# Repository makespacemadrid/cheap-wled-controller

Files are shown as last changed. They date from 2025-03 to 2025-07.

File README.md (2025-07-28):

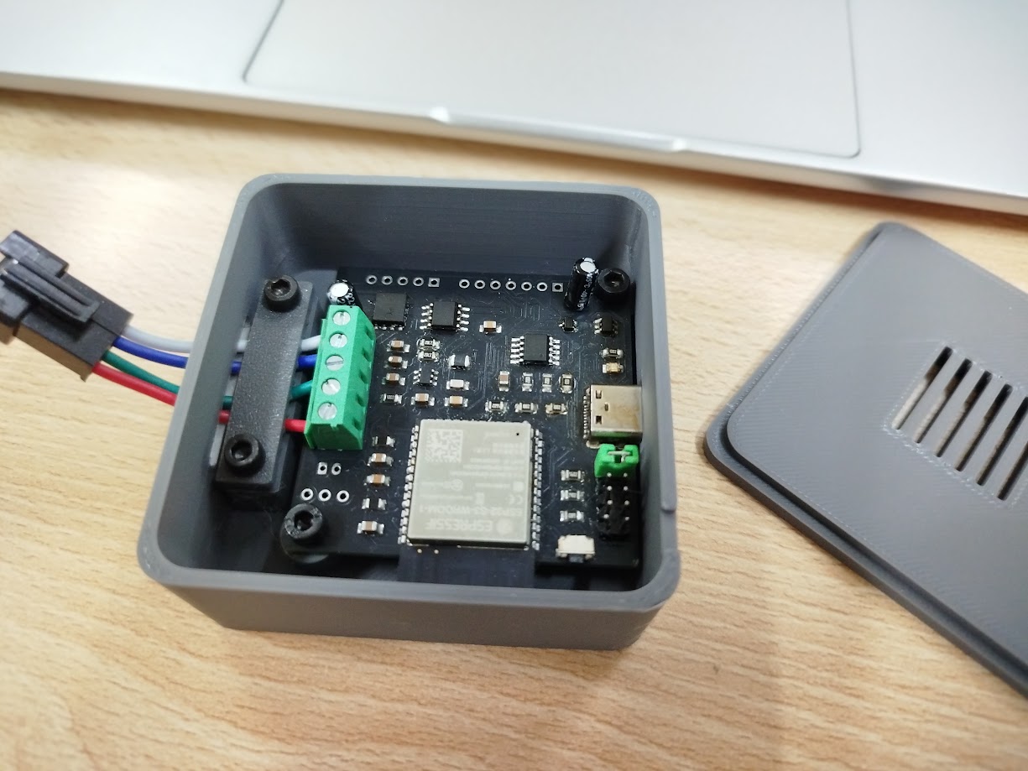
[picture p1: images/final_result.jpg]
resultado final

Este proyecto nace de una práctica con Kicad en uno de los talleres de Makespace (slides de nuestro compañero Pablo Garrido [aquí](https://docs.google.com/presentation/d/1glYFRo9XCKRI-qDjp1DA8M3mJohLk-lrxx0JoBPsboM/edit?usp=drive_link)),
donde se diseñó el esquemático y el enrutado de la pcb para posterior fabricación de la misma en JLCPCB.

Continuando con el proceso lógico de aprendizaje, 
ahora este proyecto pretende servir como una primera aproximación en la práctica de soldadura SMD (componentes de montaje superficiales), 
así como fabricación de stencil usando una CNC (maquina de control numérico).

Junto al proyecto Kicad también se encuentran los stl de la carcasa para imprimirla en 3d.

El repositorio con el proyecto Kicad: https://github.com/makespacemadrid/cheap-wled-controller718714

Esta pcb tiene la particularidad de usar para su alimentación un usb c con PD (Power delivery), lo que permite negociar diferentes votlajes y de este modo usar tiras led que trabajen a 5v, 9v, 12v, etc.

## BOM 
### PCB
- [CH224K USB PD Protocol Sink Chip IC 10Pcs/lot](https://www.aliexpress.com/item/1005005284290184.html?spm=a2g0o.order_list.order_list_main.5.21ef194dDFnpwX)
- [AMS1117 3.3](https://www.aliexpress.com/item/1005005350284100.html?spm=a2g0o.order_list.order_list_main.544.21ef194dDFnpwX)
- ESP32-S3-WROOM-1-N4R
- [TPS54202DDC](https://lcsc.com/product-detail/DC-DC-Converters_TI-TPS54202DDCR_C191884.html?s_z=n_C191884)
- [MX5014S](https://lcsc.com/product-detail/Gate-Drivers_Wuxi-Maxinmicro-MX5014S_C5359091.html?s_z=n_C5359091)
- [ESDA25W](https://lcsc.com/product-detail/ESD-and-Surge-Protection-TVS-ESD_TECH-PUBLIC-ESDA25W_C3021136.html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)
- [receptor IR](https://lcsc.com/product-detail/Infrared-Receivers_VISHAY_TSOP38238_TSOP38238_C141632.html)
- diodo led footprint 0805
- [conector usb C](https://lcsc.com/product-detail/USB-Connectors_Korean-Hroparts-Elec-TYPE-C-31-M-12_C165948.html?s_z=n_C165948)
- [pin-header](https://lcsc.com/product-detail/Pin-Headers_Megastar-ZX-PZ2-0-2-5PZZ_C7501288.html?s_z=n_C7501288)
- [mosfet canal N](https://lcsc.com/product-detail/MOSFETs_YANGJIE-YJG100N04A_C919580.html?s_z=n_C919580)

### Stencil
- [fresa 3.175mmx15Dx0.1, CN](https://www.aliexpress.com/item/4000966103866.html?spm=a2g0o.order_list.order_list_main.509.21ef194dDFnpwX)
- una lata de refresco
- cinta de carrocero
- cinta de doble cara sin espuma. La que usamos nosotros es esta, comprada en papelerías Folder:
[comprada en papelerías Folder](/images/cinta_doble_cara.png)

### Carcasa
- 4 tornillos M3x6
- 4 insertos metálicos [Length 4mm, M3 (OD 5mm)](https://es.aliexpress.com/item/1005004870993068.html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)

## Tiras led
Las tiras led compatibles con el firmware son: https://kno.wled.ge/basics/compatible-led-strips/
- La tira led que usamos en el taller es esta: [WS2813 DC5V, White PCB, 2m 60 IP65](https://es.aliexpress.com/item/1005004289391906.html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)
- Para la alimentación sirve cualquier cargador de móvil con carga rápida, IKEA tiene [estos](https://www.ikea.com/es/es/p/sjoss-cargador-usb-1-puerto-30-w-carga-rapida-50549412/) a muy buen precio
- [conectores hembra y macho JST SM de 4 pines](https://es.aliexpress.com/item/1005004615616698.html)

## Fabricación de stencil
Usaremos el software Flatcam, en el que cargamos la capa "paste top" del gerber que generamos en Kicad para enviar a fabricar la PCB.
Esta capa contiene la geometría de los pads de todos los componentes. 

El proceso lo vamos a llevar a cabo con una fresa de 30 grados y 0.1 de diámetro. Asumiendo que la lata de refresco tiene un grosor de 0.2mm.
Las capturas de los pasos a seguir son las siguientes:

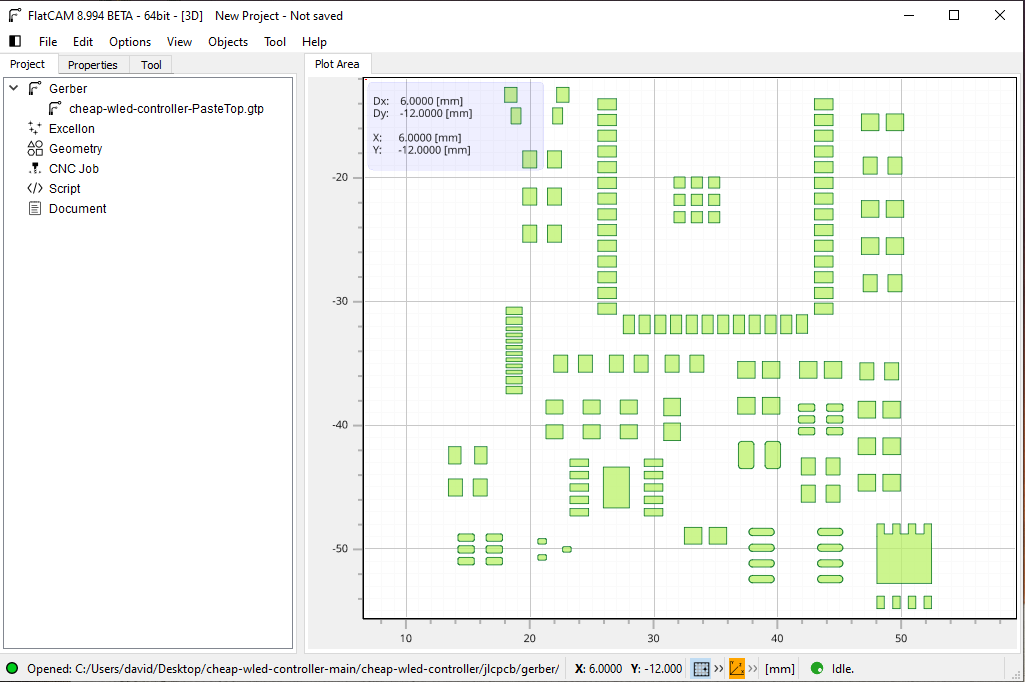
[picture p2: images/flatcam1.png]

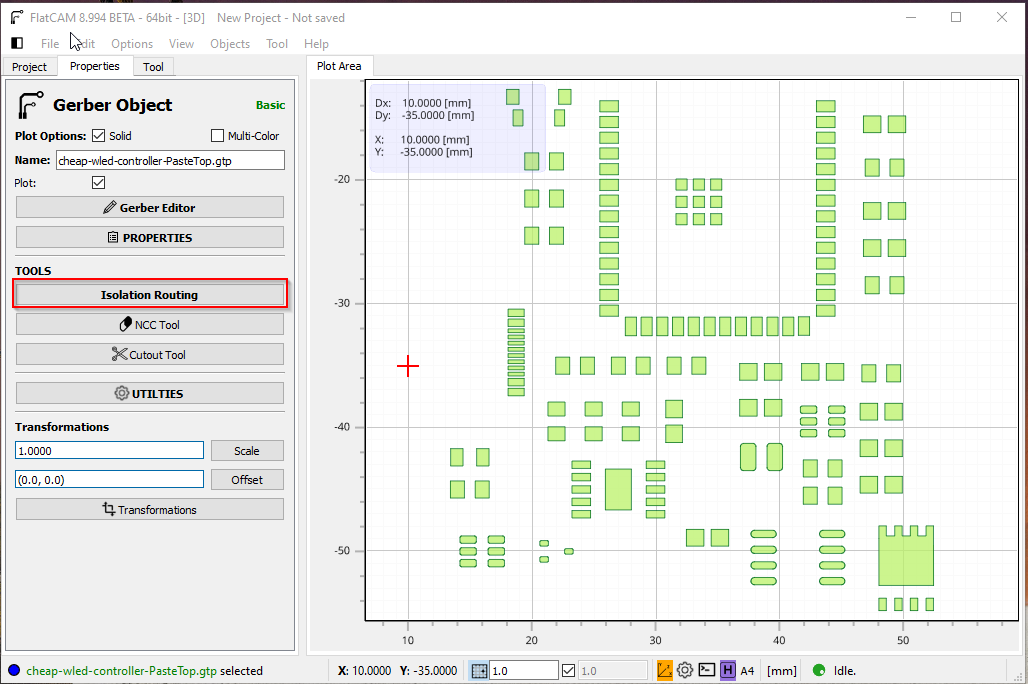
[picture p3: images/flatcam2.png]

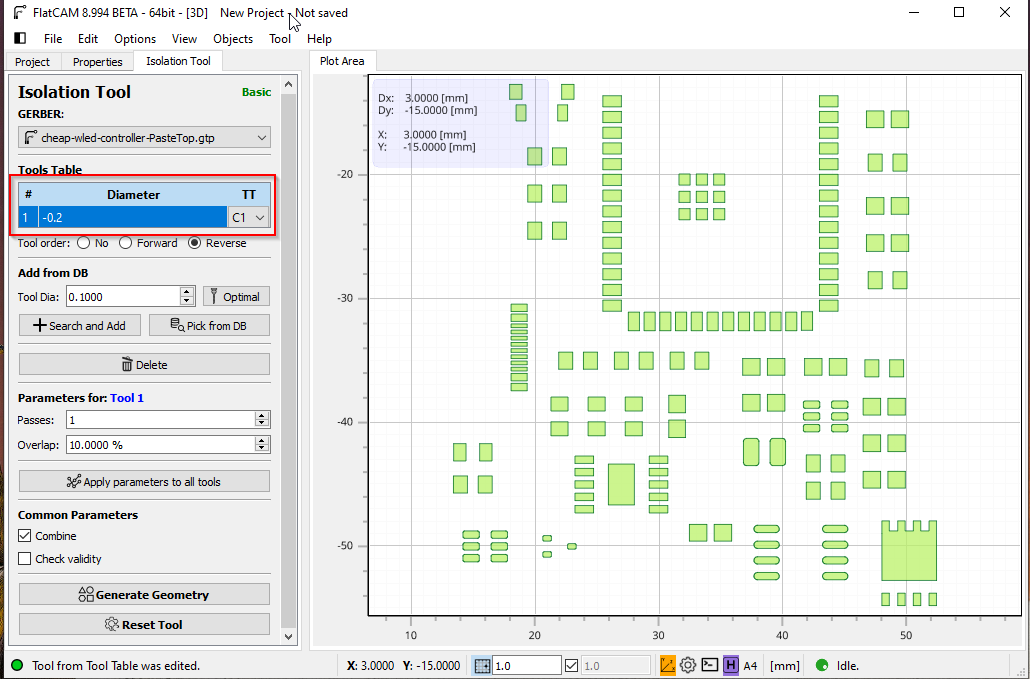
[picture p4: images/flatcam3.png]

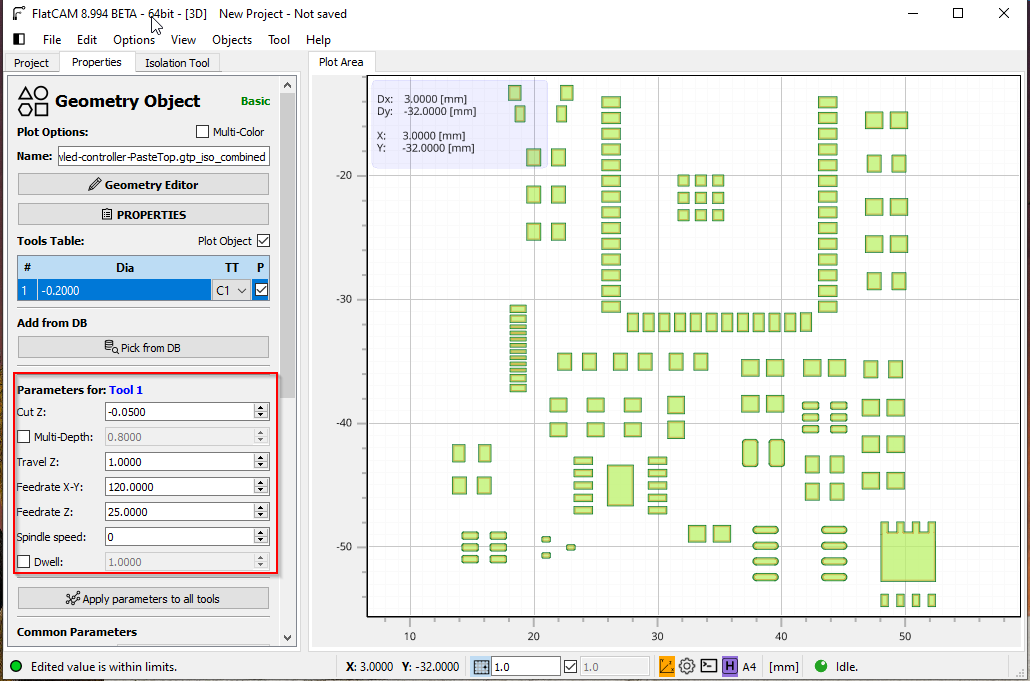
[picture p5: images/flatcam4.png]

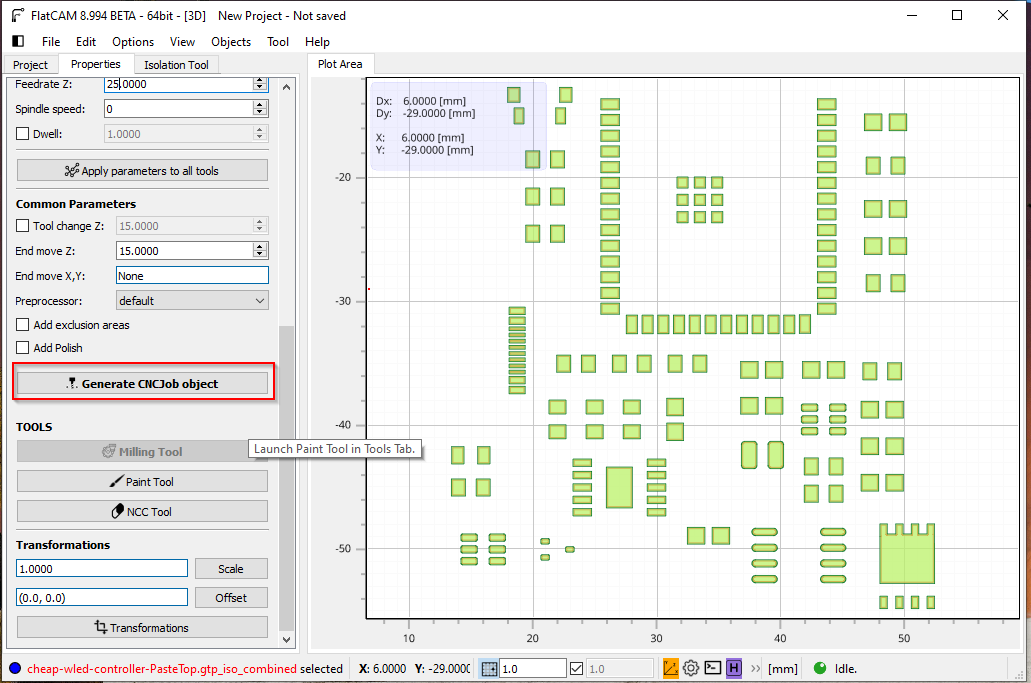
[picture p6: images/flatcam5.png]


El gcode generado finalmente lo hemos subido [aquí](/includes/paste_top.gcode).

## Flasheo y configuración de firmware WLED

### Flasheo

En nuestro caso estamos usando un esp32 s3 con 4MB, por lo que vamos a flashear desde la web: https://wled-install.github.io/

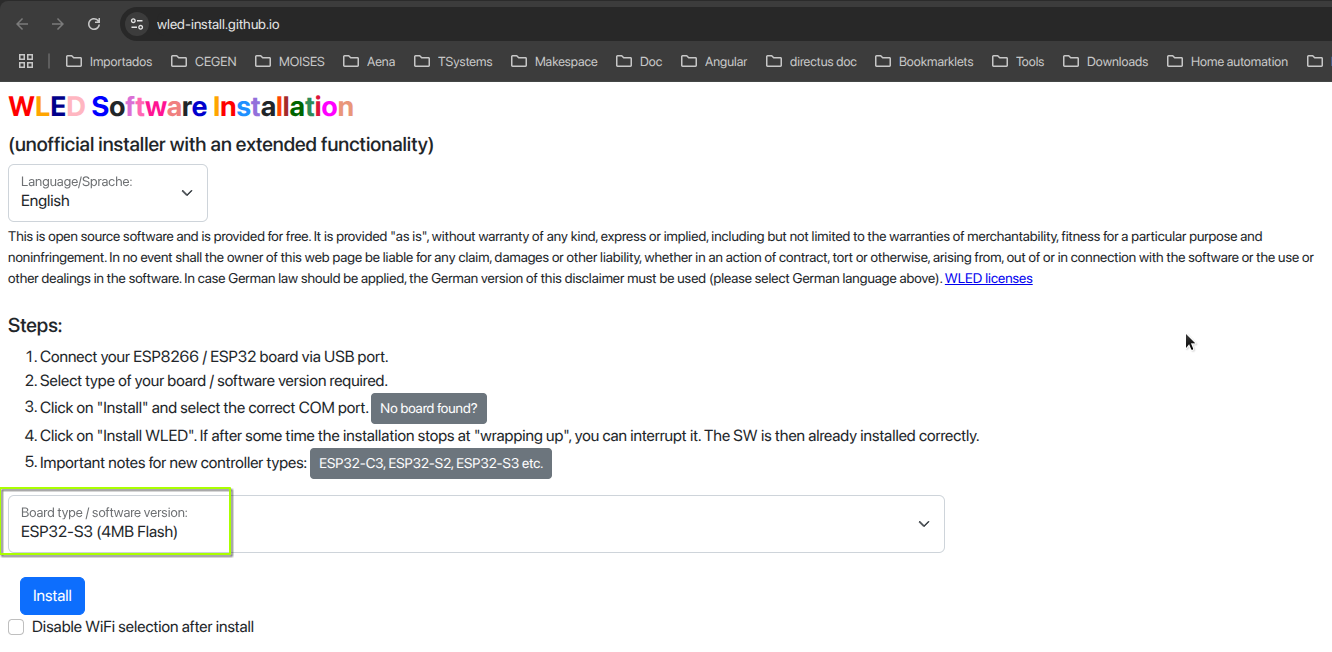
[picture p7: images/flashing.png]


### Configuración
En LED preferences:

La configuración de la tira:

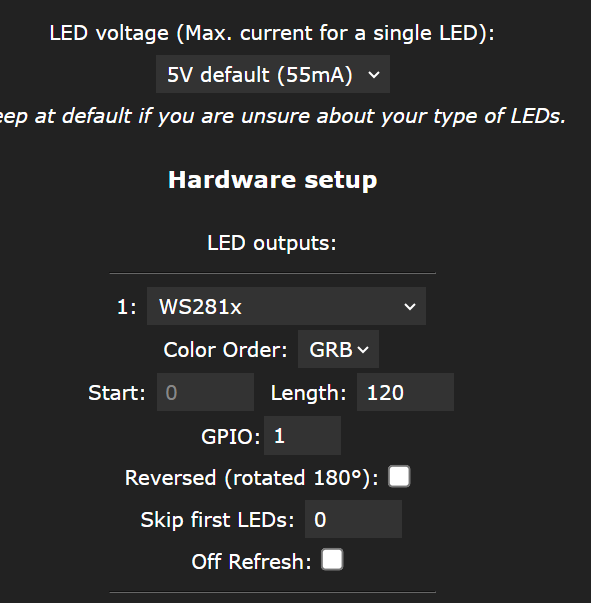
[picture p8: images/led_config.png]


La configuración del mosfet para apagar la tira:



El botón en placa permite encender y apagar la tira manualmente:



Para configurar el mando usaremos [este](/includes/18-key-ir.json) fichero json.



## Software necesario
- [Kicad](https://www.kicad.org/): Diseño pcb y generación de gerbers.
- [Flatcam](http://flatcam.org/): **Solo windows (adjuntamos el gcode ya generado)** Creación de gcode a partir del gerber para la fabricación del stencil
- [gSender](https://sienci.com/gsender/?srsltid=AfmBOopYPgWM8177GG6Q0knLP97hrF1G2skJw3ewIg3omObme7XnkDx5): Comunicación con la CNC para enviar el gcode
- [OrcaSlicer](https://orca-slicer.com/): Cualquier slicer para impresora 3d para fabricar la carcasa.

## Esquema de la placa

En este apartado se describen los componentes principales del circuito para gestionar la alimentación y regulación del voltaje de la tira LED.

---

### Información sobre el power delivery

📄 [UPD301A USB Power Delivery Operation](/datasheet/AN3265MicroChip.pdf)

📄 [A Primer on USB Type-C® and USB Power Delivery Applications and Requirements](/datasheet/PowerDeliveryTexas.pdf)

### 🔌 Conector USB-C

El conector USB-C que se utiliza en la placa tiene doce patillas con una separación muy pequeña entre cada una de ellas; además, en los dos extremos se encuentran los pines de alimentación (GND y VBUS), por lo que una mala soldadura podría generar un cortocircuito. 

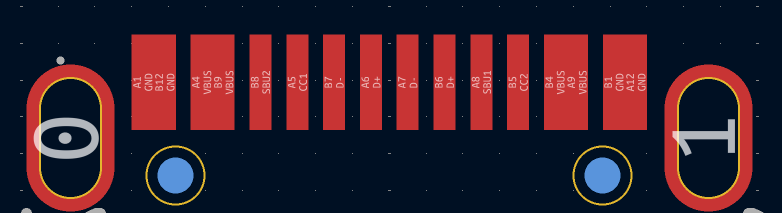
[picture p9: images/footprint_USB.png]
Connector


> **Es importante que antes de conectar la placa se mida la resistencia entre los pines de alimentación para comprobar que no haya cortocircuito 🔥.**

---

### CH224K

El CH224K es el componente encargado de gestionar el protocolo *power delibery* (PD).

📄 [Descargar datasheet](https://github.com/makespacemadrid/cheap-wled-controller/blob/main/datasheet/ch224k.pdf)

- **Encapsulado:** ESSOP-10
- **Distribución de pines:**

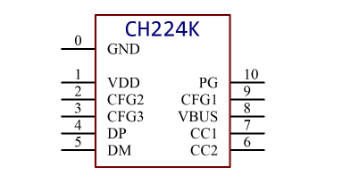
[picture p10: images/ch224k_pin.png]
Pin
  

| Pin No. | Pin name | Pin type | Pin description |
|---|---|---|---|
| 0 | GND | Power | Ground. Heat dissipation EPAD. |
| 1 | VDD | Power | Operating power input. Requires external 1uF decoupling capacitor. Connected in series with a resistor to VBUS. |
| 4, 5 | DP, DM | Input/Output | USB data line |
| 6, 7 | CC1, CC2 | Input/Output | Type-C CC data line |
| 2, 3, 9 | CFG1, CFG2, CFG3 | Analog input | Power configuration input |
| 8 | VBUS | Analog input | Voltage detection input. Connected in series with a resistor to external VBUS.  |
| 10 | PG | Open-drain output | Indicates Power Good by default. Active low. Can be customized. |

- **Configuración de voltaje de salida:**

  Los pines encargados de  configurar la salida del voltaje son el 2, el 3 y el 9. En este caso solo se utiliza el pin 9, por lo que en función de la resistencia que se conecte a este pin, el voltaje de salida variará entre 5 y 20 voltios.

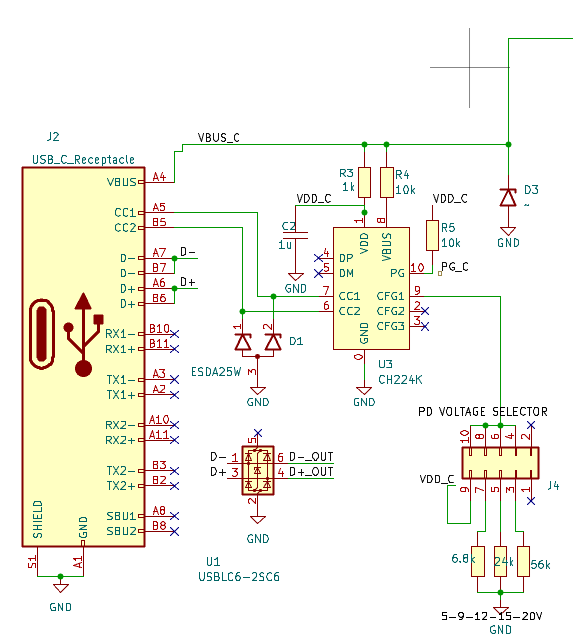
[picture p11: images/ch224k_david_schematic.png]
Schematic
  

   >Por ejemplo, si se conecta una resistencia de 10 kΩ del pin 9 a tierra, el voltaje de salida (VBUS_CONN) será de 5 V.

  | Resistance on CFG to VDD | Request-voltage |
  |--------------------------|-----------------|
  | 10KΩ                     | 5V              |
  | 20KΩ                     | 9V              |
  | 47KΩ                     | 12V             |
  | 100KΩ                    | 15V             |
  | 200KΩ                    | 20V             |

---
### TPS54202

El voltaje que sale del CH224K entra en el *buck converter* TPS54202, que será el encargado de generar los 5 voltios estables del circuito.

📄 [Descargar datasheet](/datasheet/tps54202.pdf)

- **Encapsulado:** SOT-23
  
- **Distribución de pines:**

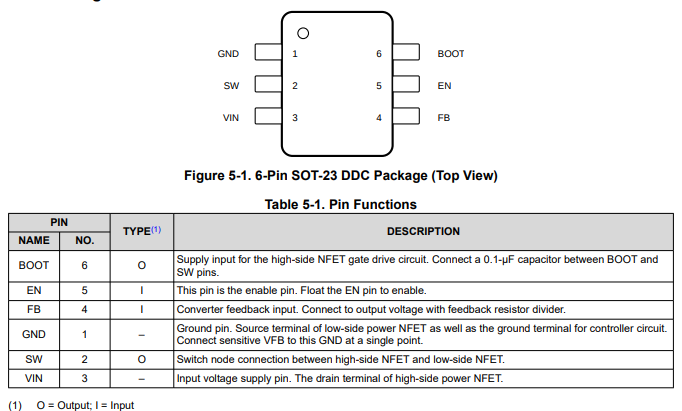
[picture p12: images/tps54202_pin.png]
Distribución de pines TPS54202
  

- **Configuración del circuito:**
  
  En el esquema del circuito se puede observar la configuración del componente, compuesta por resistencias, condensadores y la bobina L2, que mediante su carga (en forma de campo magnético) y descarga genera la corriente necesaria para alimentar los condensadores, que estabilizarán los 5 voltios de salida (+5V).

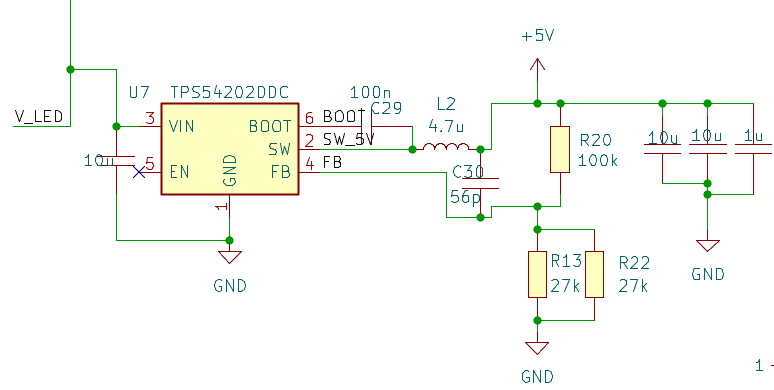
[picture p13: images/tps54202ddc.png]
  

---
### AMS1117 3-3V

Una vez que se ha generado el voltaje +5V, el regulador de voltaje lineal (LDO) AMS1117 comienza a trabajar para entregar los 3,3V. Hay que tener en cuenta que la corriente máxima que puede entregar este regulador es de 1A. 

📄 [Descargar datasheet](/datasheet/ams1117.pdf)

- **Distribución de pines:**

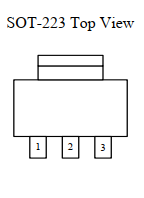
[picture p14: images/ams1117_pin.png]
Distribución de pines AMS1117
  

  > PIN 1: GND
  >
  > PIN 2: VOUT
  >
  > PIN 3: VDD

- **Configuración del circuito:**
  
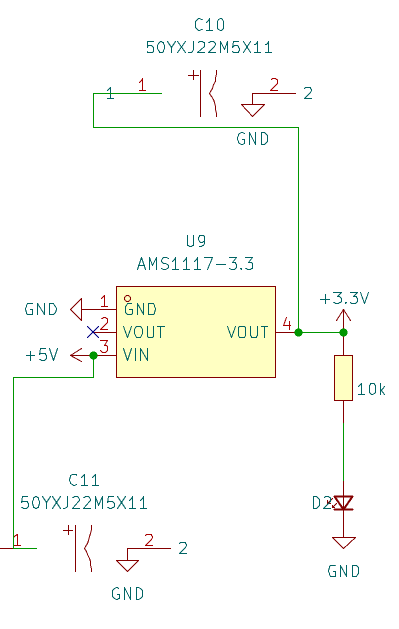
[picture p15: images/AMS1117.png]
  

---
### ESP32-S3-WROOM-1-N4R2

📄 [Descargar datasheet](/datasheet/esp32-s3.pdf)

- **Distribución de pines:**

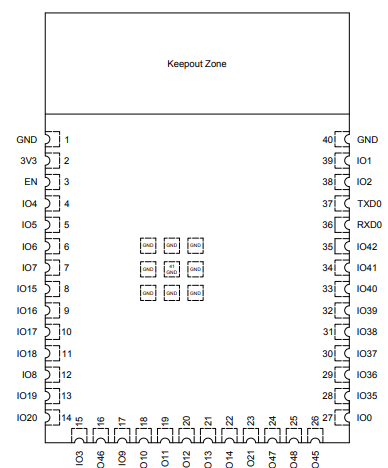
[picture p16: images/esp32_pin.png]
Distribución de pines ESP32-S3-WROOM-1-N4R2
  

- **Configuración del circuito:**
  
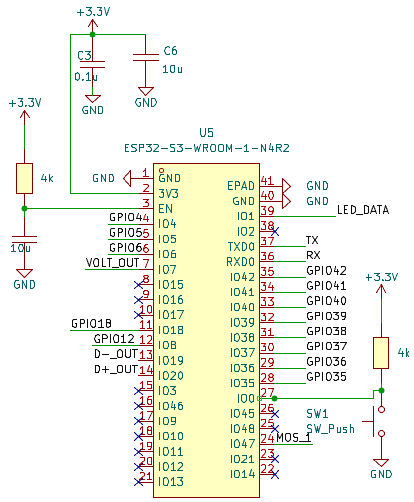
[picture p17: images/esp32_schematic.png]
Schematic
  

---
### MX5014S

 La tira LED se alimenta a través del voltaje que se genera en el MOSFET Q3, que está controlado por el MX5014S, y que a su vez responde del IO47 del ESP32.

📄 [Descargar datasheet](/datasheet/mx5014s.pdf)

- **Distribución de pines:**
  
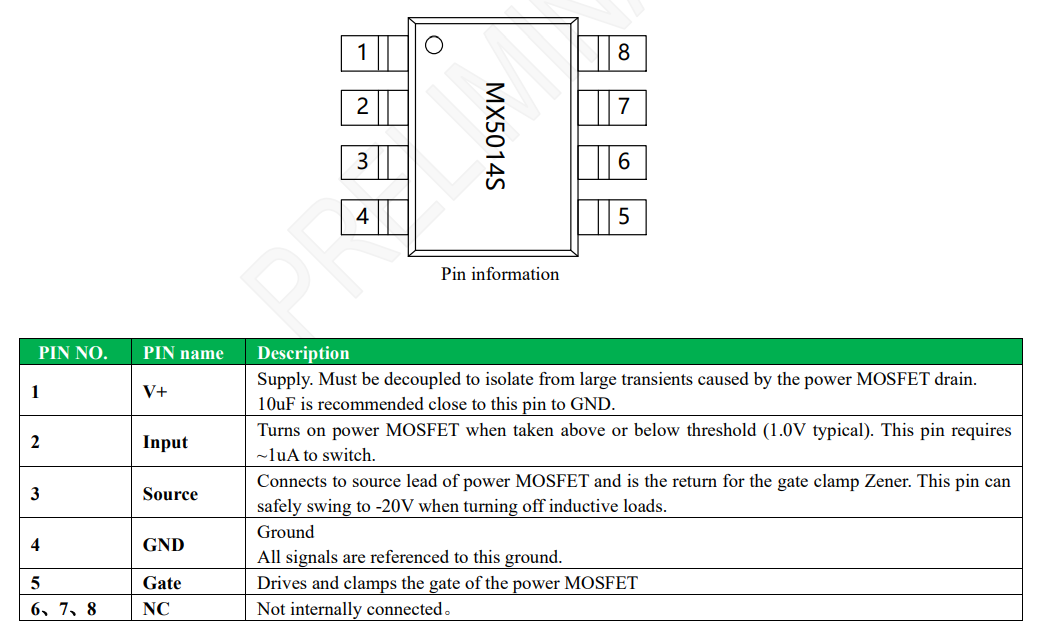
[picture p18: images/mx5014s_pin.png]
Distribución de los pines
  

- **Configuración del circuito:**
  
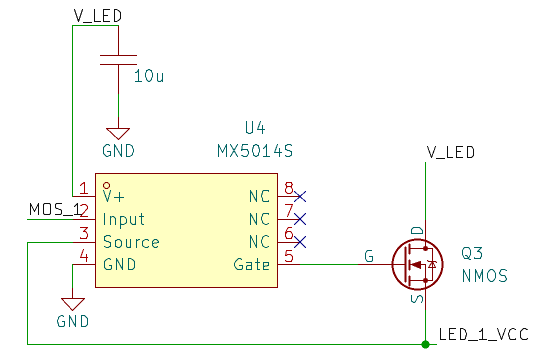
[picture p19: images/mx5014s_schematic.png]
Schematic
  

## Líneas de voltaje principales

|Línea|Voltaje|Componente|
|-----|---|---|
|V_LED_|5-20V|CH224K|
|+5V|5V|TPS54202|
|+3.3V|3.3V|AMS1117|
|LED_1_VCC|5-20V|Q3

---
## Stencil con los valores de los componentes

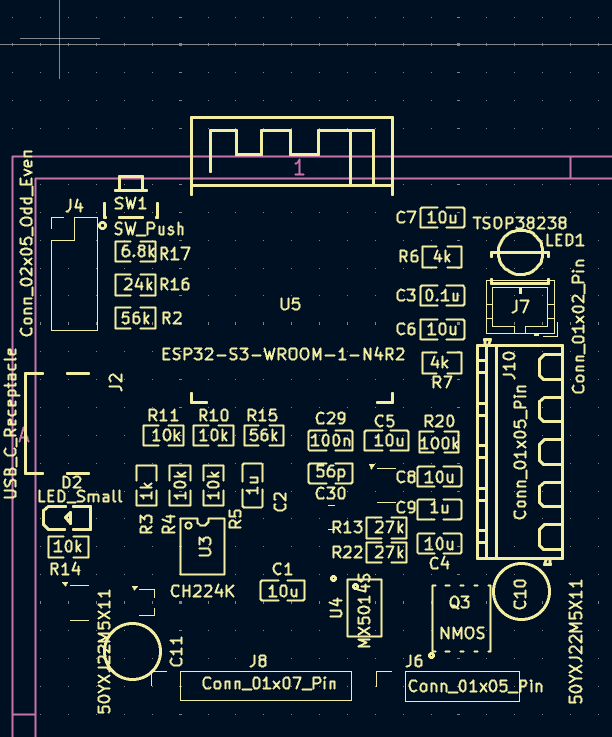
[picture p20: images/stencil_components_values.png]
Stencil


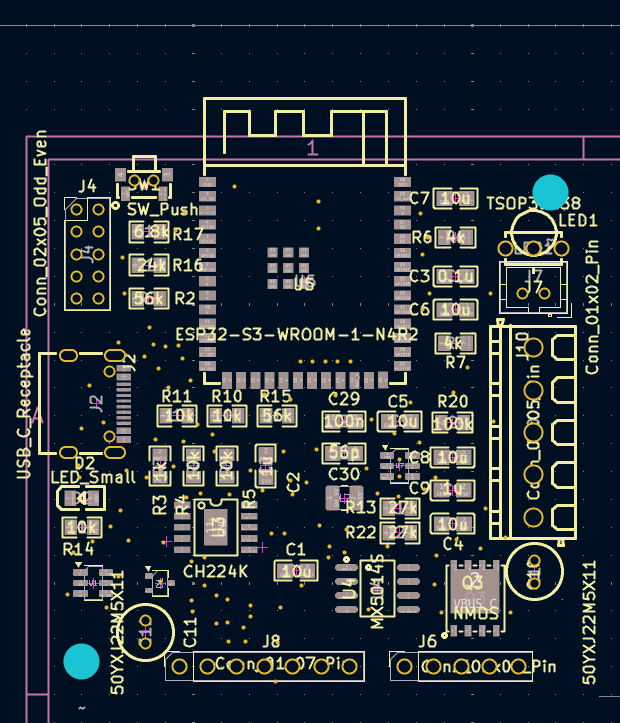
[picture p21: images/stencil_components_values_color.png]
Stencil

---
## Autores
- [David Poza](http://github.com/davidpoza)
- [Jose David](http://github.com/jose8david)

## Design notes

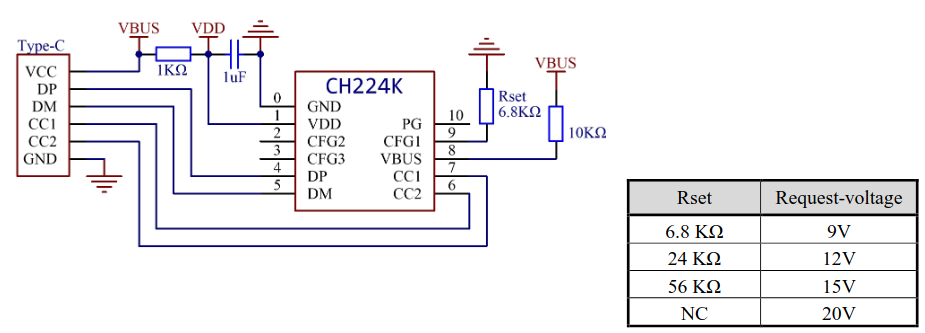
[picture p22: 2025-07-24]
images/ch224k_schematic.png

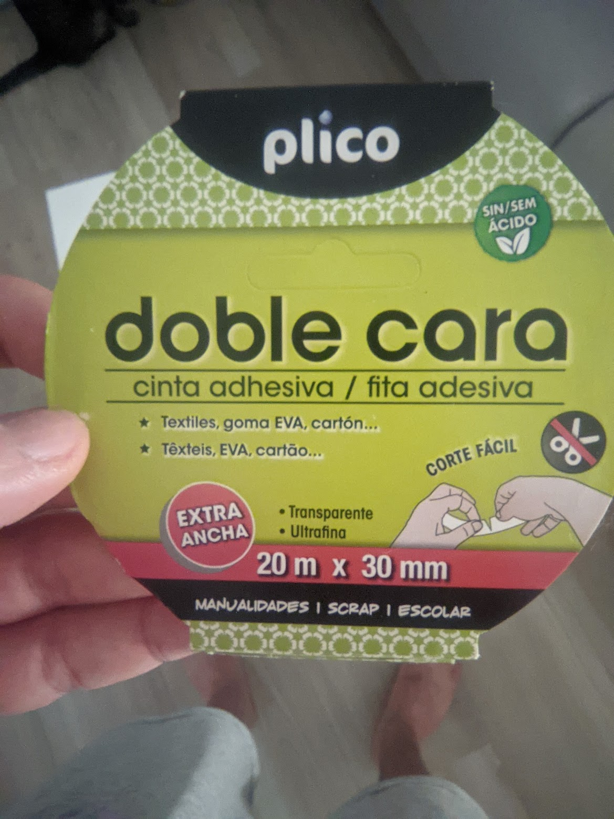
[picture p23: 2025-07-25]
images/cinta_doble_cara.png

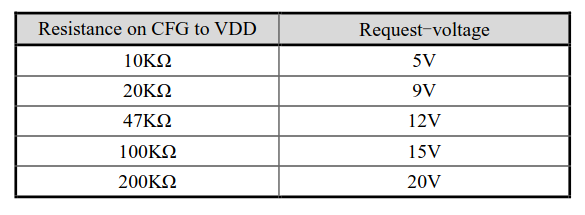
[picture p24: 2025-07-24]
images/ch224k_config_resistances.png

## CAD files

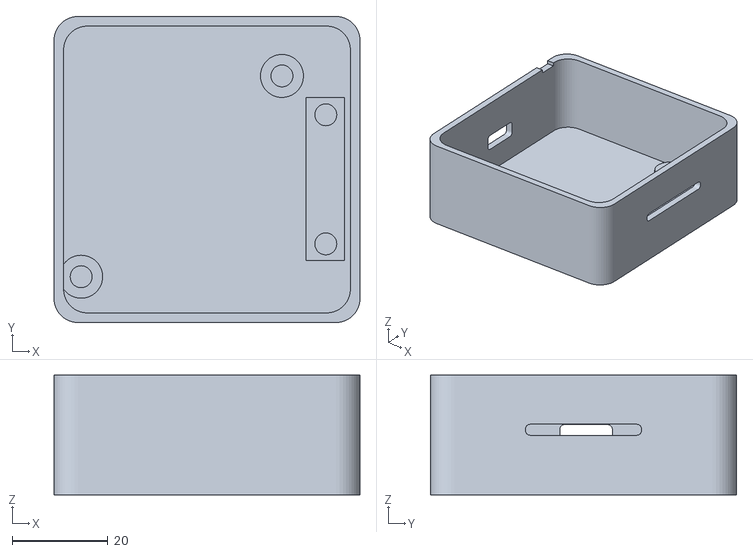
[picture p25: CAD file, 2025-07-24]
case stl/case.stl
64.0 x 64.0 x 25.0

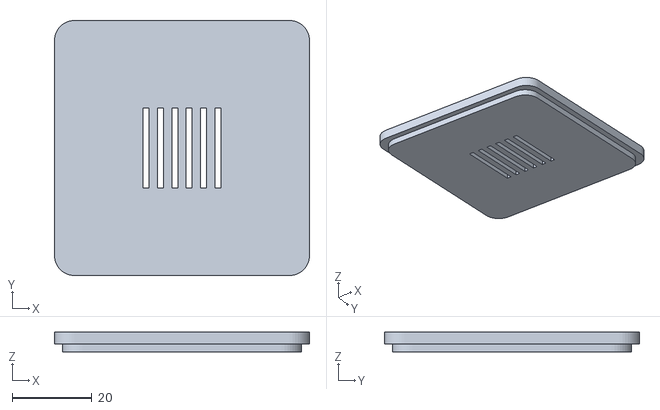
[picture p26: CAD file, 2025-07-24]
case stl/lid.stl
64.0 x 64.0 x 5.00

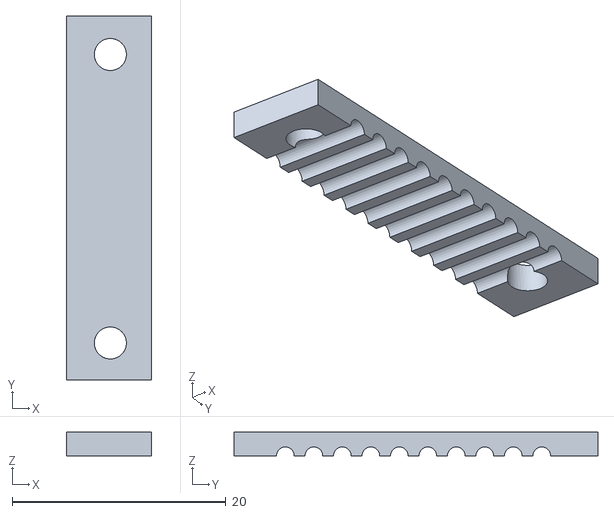
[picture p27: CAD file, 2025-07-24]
case stl/cable clamp.stl
8.00 x 34.1 x 2.20

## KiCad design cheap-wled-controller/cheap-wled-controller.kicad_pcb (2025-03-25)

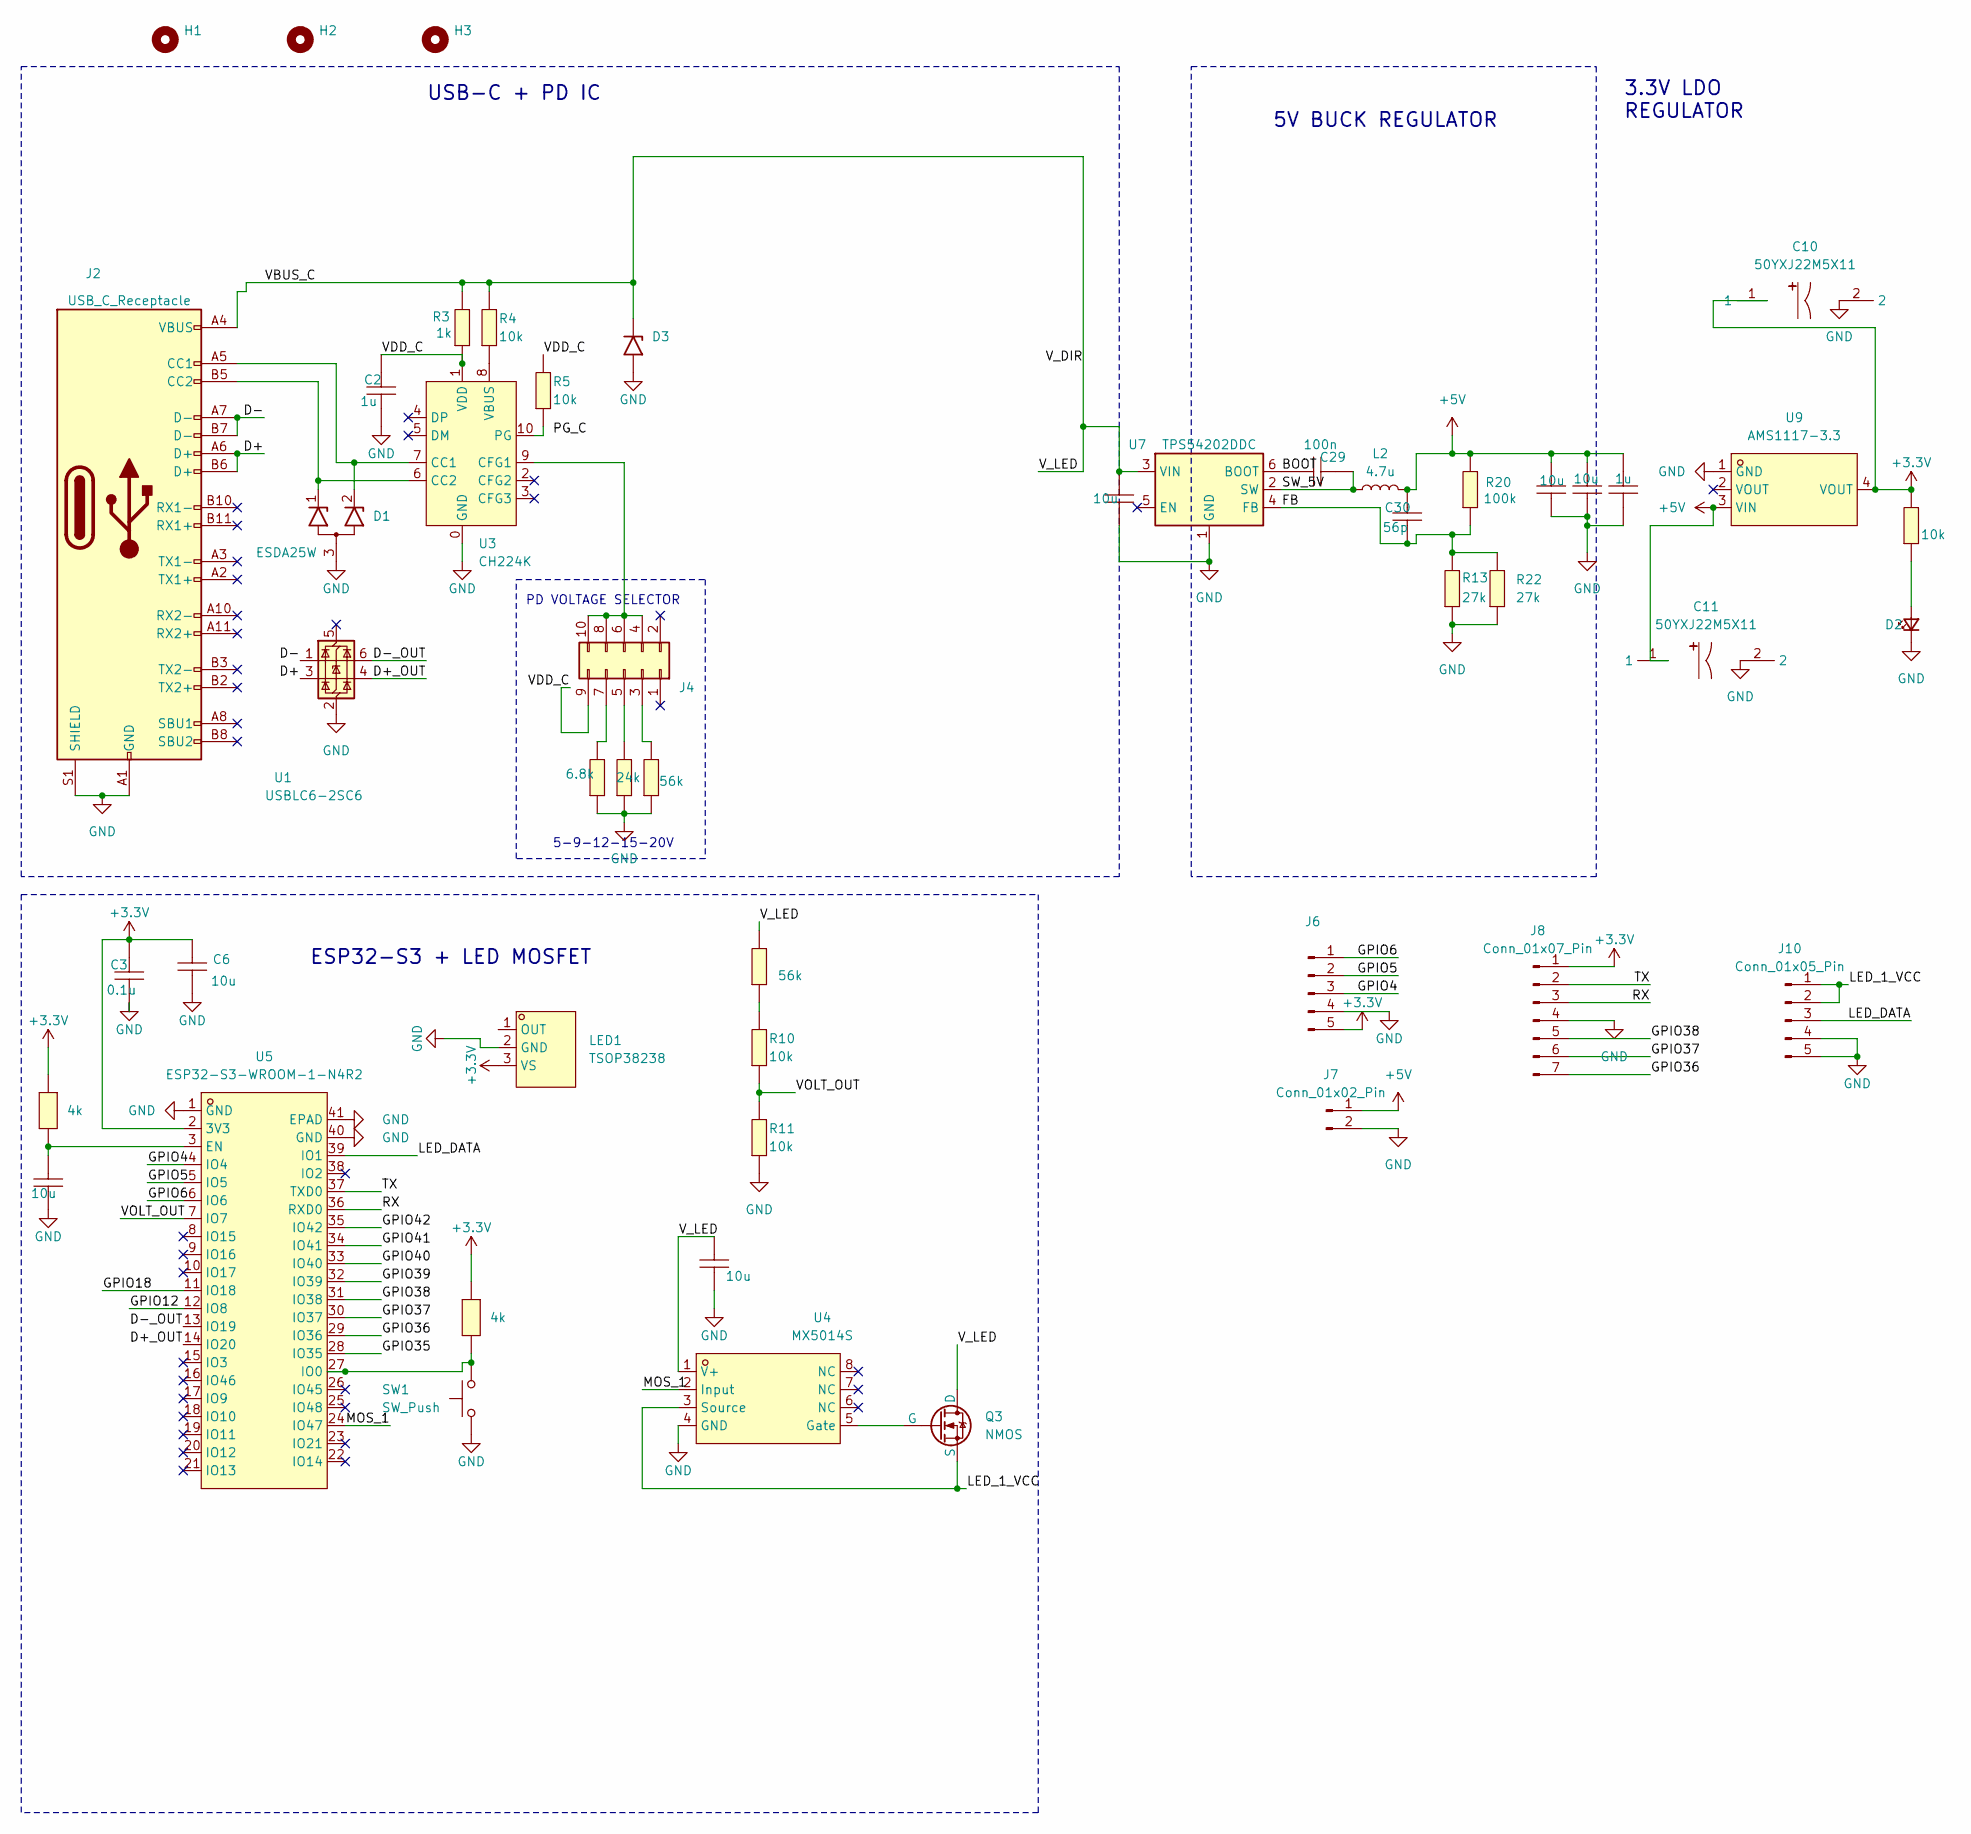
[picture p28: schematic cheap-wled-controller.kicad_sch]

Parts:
C1, C4, C5, C6, C7, C8: 10u; C0805; LCSC Part C1713
C2, C9: 1u; C0805; LCSC Part C215803
C3: 0.1u; C0805; LCSC Part C476766
C10, C11: 50YXJ22M5X11; CAP-TH_BD5.0-P2.00-D0.5-FD-1; LCSC Part C432364
C29: 100n; C0805; LCSC Part C476766
C30: 56p; C0805; LCSC Part C1828
D1: ESDA25W; SOT-323_SC-70; LCSC C3021136
D2: LED_Small; LED0805-R-RD; LCSC C5123548
D3: D_SMA; LCSC C383698
H1, H2, H3: MountingHole_3.2mm_M3
J2: USB_C_Receptacle; USB-C_SMD-TYPE-C-31-M-12; LCSC C165948
J4: Conn_02x05_Odd_Even; PinHeader_2x05_P2.00mm_Vertical; LCSC C7501288
J6: Conn_01x05_Pin; PinSocket_1x05_P2.54mm_Vertical
J7: Conn_01x02_Pin; JST_PH_B2B-PH-K_1x02_P2.00mm_Vertical; LCSC C131337
J8: Conn_01x07_Pin; PinSocket_1x07_P2.54mm_Vertical
J10: Conn_01x05_Pin; CONN-TH_5P-P3.81_KF124-3.81-5P; LCSC C72336
L2: 4.7u; L_1008_2520Metric; LCSC C91237
LED1: TSOP38238; SENSOR-TG_TSOP38236; LCSC Part C141632
Q3: NMOS; DFN-8_L5.9-W5.2-P1.27-LS6.2-BL; LCSC C919580
R2, R15: 56k; R0805; LCSC Part C17756
R3: 1k; R0805; LCSC Part C17513
R4, R5, R10, R11, R14: 10k; R0805; LCSC Part C17414
R6, R7: 4k; R0805; LCSC Part C2828855
R13, R22: 27k; R0805; LCSC Part C114533
R16: 24k; R0805; LCSC Part C17575
R17: 6.8k; R0805; LCSC Part C17772
R20: 100k; R0805; LCSC Part C149504
SW1: SW_Push; SW-SMD_TSA245G00D-250; LCSC C2846758
U1: USBLC6-2SC6; SOT-23-6; LCSC C2827654
U3: CH224K; ESSOP-10_L4.9-W3.9-P1.0-LS6.0-TL-EP; LCSC C970725
U4: MX5014S; SOIC-8_L4.9-W3.9-P1.27-LS6.0-BL; LCSC Part C5359091
U5: ESP32-S3-WROOM-1-N4R2; WIRELM-SMD_ESP32-S3-WROOM-1; LCSC Part C2913203
U7: TPS54202DDC; SOT-23-6; LCSC C191884
U9: AMS1117-3.3; SOT-223-3_L6.5-W3.4-P2.30-LS7.0-BR; LCSC Part C6186

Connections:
+3.3V: C3.2, C6.2, C10.1, J6.5, J8.1, LED1.3 (VS), R6.1, R7.1, R14.2, U5.2 (3V3), U9.4 (VOUT)
+5V: C4.2, C8.2, C9.2, C11.1, C30.2, J7.1, L2.2, R20.2, U9.3 (VIN)
/BOOT: C29.2, U7.6 (BOOT)
/D+: J2.A6 (D+), J2.B6 (D+), U1.3 (I/O2)
/D+_OUT: U1.4 (I/O2), U5.14 (IO20)
/D-: J2.A7 (D-), J2.B7 (D-), U1.1 (I/O1)
/D-_OUT: U1.6 (I/O1), U5.13 (IO19)
/FB: C30.1, R13.2, R20.1, R22.2, U7.4 (FB)
/GPIO4: J6.3, U5.4 (IO4)
/GPIO5: J6.2, U5.5 (IO5)
/GPIO6: J6.1, U5.6 (IO6)
/GPIO12: U5.12 (IO8)
/GPIO18: U5.11 (IO18)
/GPIO35: U5.28 (IO35)
/GPIO36: J8.7, U5.29 (IO36)
/GPIO37: J8.6, U5.30 (IO37)
/GPIO38: J8.5, U5.31 (IO38)
/GPIO39: U5.32 (IO39)
/GPIO40: U5.33 (IO40)
/GPIO41: LED1.1 (OUT), U5.34 (IO41)
/GPIO42: U5.35 (IO42)
/LED_1_VCC: J10.1, J10.2, Q3.3 (S), U4.3 (Source)
/LED_DATA: J10.3, U5.39 (IO1)
/MOS_1: U4.2 (Input), U5.24 (IO47)
/RX: J8.3, U5.36 (RXD0)
/SW_5V: C29.1, L2.1, U7.2 (SW)
/TX: J8.2, U5.37 (TXD0)
/VBUS_C: C1.2, C5.2, D3.1 (A1), J2.A4 (VBUS), J2.A9 (VBUS), J2.B4 (VBUS), J2.B9 (VBUS), Q3.2 (D), R3.2, R4.2, R15.2, U4.1 (V+), U7.3 (VIN)
/VDD_C: C2.2, J4.9, R3.1, R5.2, U3.1 (VDD)
/VOLT_OUT: R10.1, R11.2, U5.7 (IO7)
GND: C1.1, C2.1, C3.1, C4.1, C5.1, C6.1, C7.1, C8.1, C9.1, C10.2, C11.2, D1.3 (A), D2.1 (K), D3.2 (A2), J2.0, J2.1, J2.2, J2.3, J2.A1 (GND), J2.A12 (GND), J2.B1 (GND), J2.B12 (GND), J2.S1 (SHIELD), J6.4, J7.2, J8.4, J10.4, J10.5, LED1.2 (GND), R2.1, R11.1, R13.1, R16.1, R17.1, R22.1, SW1.1, U1.2 (GND), U3.0 (GND), U3.11, U4.4 (GND), U5.1 (GND), U5.40 (GND), U5.41 (EPAD), U7.1 (GND), U9.1 (GND)
unnamed: D1.1 (K1), J2.B5 (CC2), U3.6 (CC2)
unnamed: D1.2 (K2), J2.A5 (CC1), U3.7 (CC1)
unnamed: D2.2 (A), R14.1
unnamed: J4.3, R2.2
unnamed: J4.5, R16.2
unnamed: J4.7, R17.2
unnamed: J4.4, J4.6, J4.8, J4.10, U3.9 (CFG1)
unnamed: Q3.1 (G), U4.5 (Gate)
unnamed: R10.2, R15.1
unnamed: R5.1, U3.10 (PG)
unnamed: R4.1, U3.8 (VBUS)
unnamed: C7.2, R6.2, U5.3 (EN)
unnamed: R7.2, SW1.2, U5.27 (IO0)

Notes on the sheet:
ESP32-S3 + LED MOSFET
USB-C + PD IC
5V BUCK REGULATOR
5-9-12-15-20V
PD VOLTAGE SELECTOR
3.3V LDO REGULATOR

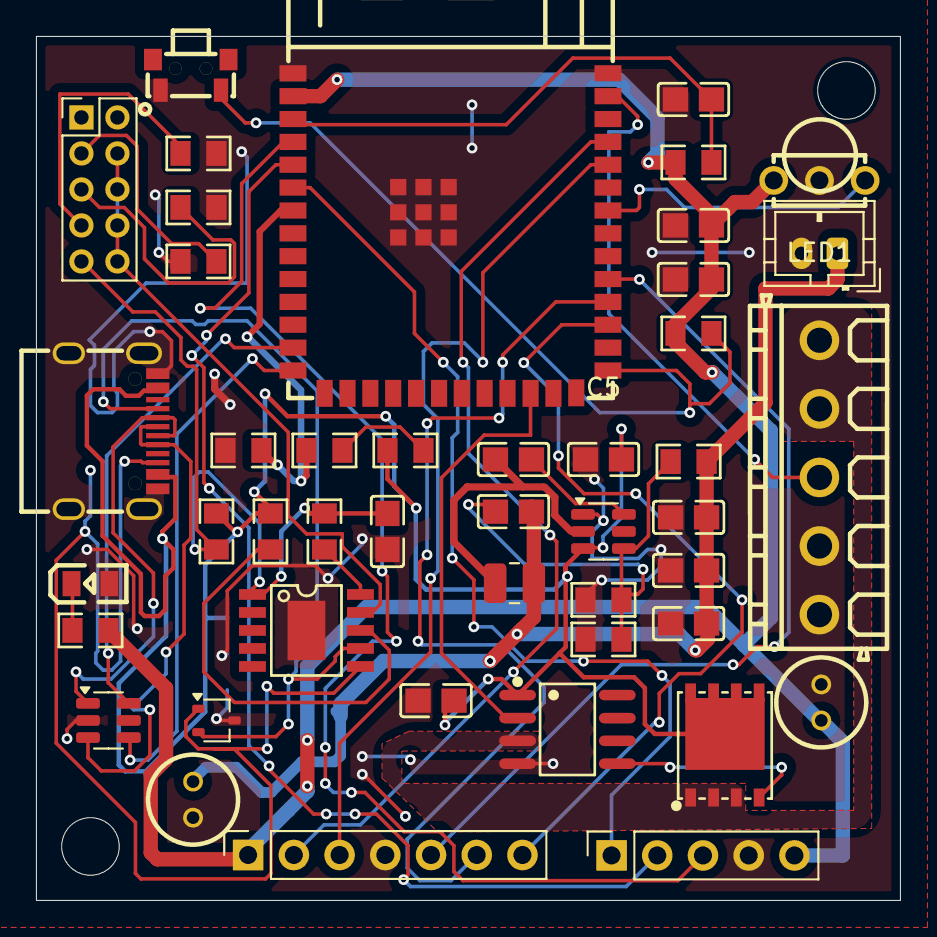
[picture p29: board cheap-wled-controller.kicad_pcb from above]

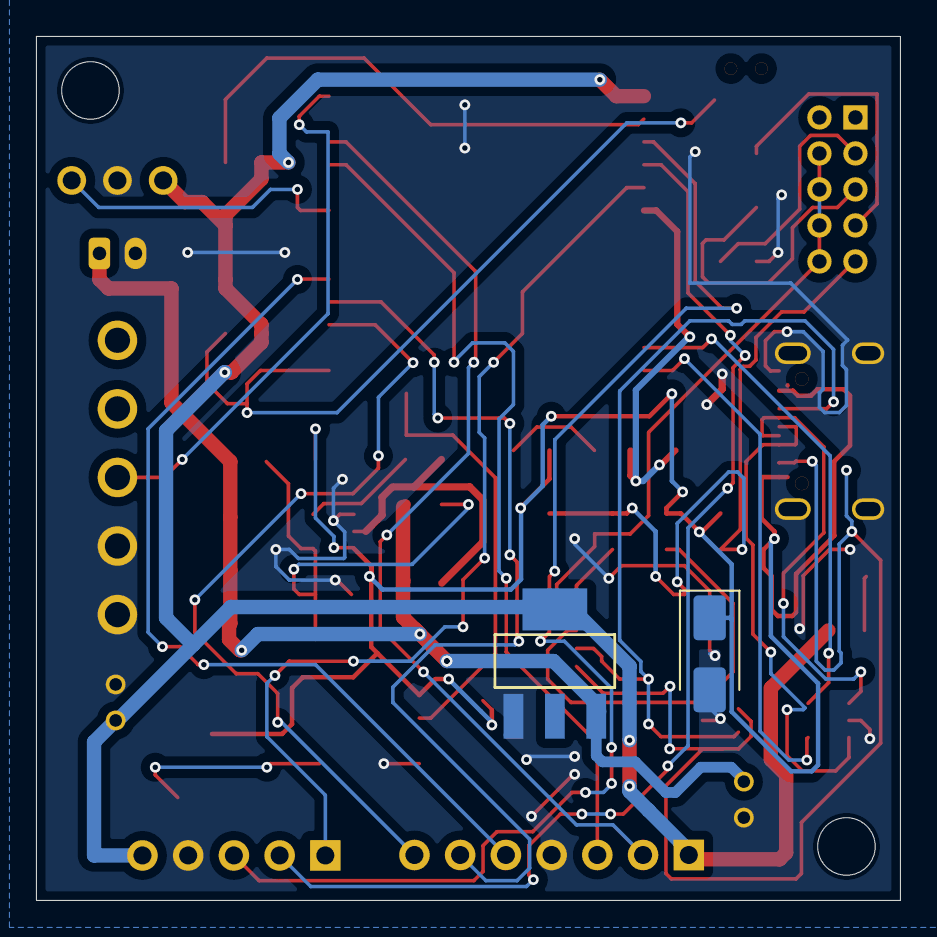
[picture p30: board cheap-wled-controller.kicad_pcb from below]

Board: 2 copper layers, 48.0 x 48.0 mm, 49 parts (2 on the bottom side), 38 nets.

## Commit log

2025-01-26 voltage selector
    [cheap-wled-controller.kicad_sch]
2025-01-26 footprint problem solved
    [cheap-wled-controller.kicad_pcb, cheap-wled-controller.kicad_sch]
2025-01-29 etapa de 5v a 3v
    [cheap-wled-controller.kicad_sch]
2025-02-02 refactor using 0805 components
    [cheap-wled-controller.kicad_sch]
2025-02-02 esp32 s3
    [cheap-wled-controller.kicad_sch]
2025-02-04 all footprints added
    [cheap-wled-controller.kicad_sch]
2025-02-04 leds added
    [cheap-wled-controller.kicad_sch]
2025-02-06 some traces
    [cheap-wled-controller.kicad_pcb]
2025-02-08 pcb fixes
    [cheap-wled-controller.kicad_pcb, cheap-wled-controller.kicad_sch, freerouting.dsn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]
2025-02-15 drc fixes
    [cheap-wled-controller.kicad_pcb]
2025-02-16 added gerber
    [cheap-wled-controller-CmtUser.gbr, cheap-wled-controller-CuBottom.gbl, cheap-wled-controller-CuTop.gtl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]
2025-02-19 added panelized gerber
    [cheap-wled-controller-CmtUser.gbr, cheap-wled-controller-CuBottom.gbl, cheap-wled-controller-CuTop.gtl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]
2025-02-19 added some GND for the esp32
    [cheap-wled-controller.kicad_pcb, cheap-wled-controller.kicad_sch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]
2025-02-19 right position for the holes
    [cheap-wled-controller.kicad_pcb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]
2025-03-19 new design mini 5x5
    [cheap-wled-controller.kicad_pcb, cheap-wled-controller.kicad_sch]
2025-03-22 all tracks connected
    [cheap-wled-controller.kicad_pcb]
2025-03-23 added capacitors for ams1117 and TSOP38238
    [cheap-wled-controller.kicad_pcb, cheap-wled-controller.kicad_sch]
2025-07-20 added case stl
    [cable clamp.stl, case.stl, lid.stl]
2025-07-24 Información sobre el componente ch224k
2025-07-24 added BOM
2025-07-24 Componentes del circuito: CH224K y buck converted
2025-07-25 Componentes principales del circuito
2025-07-25 Esquema de la placa completo
2025-07-25 Líneas de voltaje
2025-07-25 added more items in BOM
2025-07-25 Actualizo con la información del esquemático
2025-07-28 Añado información sobre el power delivery
